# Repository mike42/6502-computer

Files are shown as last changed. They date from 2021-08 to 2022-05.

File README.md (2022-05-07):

# 6502 computer

This repository contains the hardware and software for my home-built 65C02-based computer. At its heart, this computer is a 1980's design, and is approximately as powerful as the Apple II. It is powered over USB, and operated via a serial connection.

It features an SD card interface, simple audio interface, and two user-selectable ROMs. One ROM contains a port of EhBASIC, which is the only proprietary component in this repository. The other ROM contains a shell, written from scratch to be free and open source, which can be used to load machine-language programs from a modern PC.

Take a look at the [hardware/](https://github.com/mike42/6502-computer/tree/main/hardware) directory for how it's made, or [rom/](https://github.com/mike42/6502-computer/tree/main/rom) for the firmware source code.

### Basic specs

- 1.8432 MHz 65C02 processor
- 32 KiB RAM
- 32 KiB ROM in two 16 KiB banks
- 65C22 VIA (general purpose I/O) chip
- 65C51N ACIA (UART) interface
- Custom PCB and 3D printed case

### Image of completed build

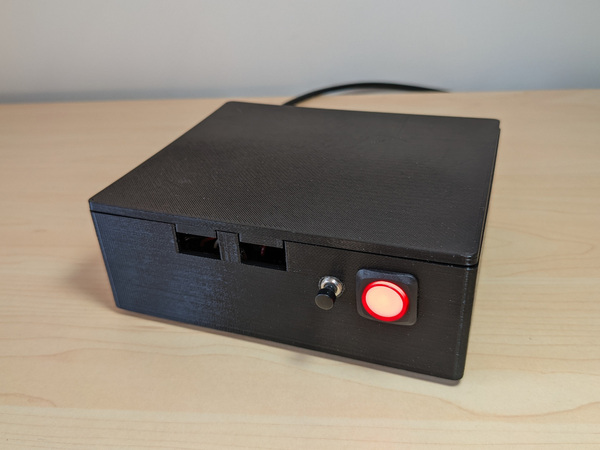
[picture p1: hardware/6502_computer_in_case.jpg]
Completed project


## Blog series

This project started out on breadboards, and I have been blogging about it as I have progressed the hardware, software, and my electronics knowlege. Posts I've written about this project include:

- [IntelliJ plugin for 6502 assembly language](https://mike42.me/blog/2021-05-intellij-plugin-for-6502-assembly-language)
- [Building a 6502 computer](https://mike42.me/blog/2021-07-building-a-6502-computer)
- [Adding a serial port to my 6502 computer](https://mike42.me/blog/2021-07-adding-a-serial-port-to-my-6502-computer)
- [Upgrades and improvements to my 6502 computer](https://mike42.me/blog/2021-08-upgrades-and-improvements-to-my-6502-computer)
- [Porting BASIC to my 6502 computer](https://mike42.me/blog/2021-09-porting-basic-to-my-6502-computer)
- [6502 computer – from breadboard to PCB](https://mike42.me/blog/2021-09-6502-computer-from-breadboard-to-pcb)
- [Re-creating the world’s worst sound card](https://mike42.me/blog/2021-10-re-creating-the-worlds-worst-sound-card)
- [Designing a 3D printed enclosure for my KiCad project in Blender](https://mike42.me/blog/2021-11-designing-a-3d-printed-enclosure-for-my-kicad-project-in-blender)
- [Implementing the XMODEM protocol for file transfer](https://mike42.me/blog/2021-12-implementing-the-xmodem-protocol-for-file-transfer)
- [Adding an SD card reader to my 6502 computer](https://mike42.me/blog/2021-12-adding-an-sd-card-reader-to-my-6502-computer)
- [Assembling my 6502 computer](https://mike42.me/blog/2012-12-assembling-my-6502-computer)
- [Rendering my 6502 computer project in Blender](https://mike42.me/blog/2022-01-rendering-my-6502-computer-project-in-blender)

## Licenses & acknowledgement

With the exception of the files noted below, this work is © 2021 Michael Billington, and is licensed under a [Creative Commons Attribution 4.0 International License](http://creativecommons.org/licenses/by/4.0/).

The design is an extension of [Ben Eater's 6502 computer tutorial](https://eater.net/6502), which is itself based on the work of the [6502.org](http://www.6502.org/) community.

### 6502 KiCad Library

The files `hardware/kicad/65xx.dcm` and `hardware/kicad/65xx.lib` are modified versions of the [6502 KiCad Library](https://github.com/Alarm-Siren/6502-kicad-library). Copyright 2018, Nicholas Parks Young. All Rights Reserved. The 6502 KiCad Library library is licensed under the GNU LGPL v2.1, which can be found in file `licenses/LGPL.txt`.

### EhBASIC

The files in `rom/basic/` are derived from EhBASIC, developed by Lee Davidson. The EhBASIC license allows for non-commerical use only. The most recent release and manual is hosted [here](https://github.com/Klaus2m5/6502_EhBASIC_V2.22), and a mirror of Lee's website can be found [here](http://retro.hansotten.nl/6502-sbc/lee-davison-web-site/).

> EhBASIC is free but not copyright free. For non commercial use there is only one
> restriction, any derivative work should include, in any binary image distributed,
> the string "Derived from EhBASIC" and in any distribution that includes human
> readable files a file that includes the above string in a human readable form
> e.g. not as a comment in an HTML file.

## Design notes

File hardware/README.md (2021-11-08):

# 6502 computer hardware

This directory contains information about the hardware side of this project.

- [kicad/](https://github.com/mike42/6502-computer/tree/main/hardware/kicad) - CAD source files for schematic and PCB
- [gerber/](https://github.com/mike42/6502-computer/tree/main/hardware/gerber/) - PCB manufacturing files 
- [6502_computer_schematic.pdf](https://github.com/mike42/6502-computer/tree/main/hardware/6502_computer_schematic.pdf) - Human-readable schematic
- [case/](https://github.com/mike42/6502-computer/tree/main/hardware/case/) - STL files for 3D printed computer case.
- Parts list (below)

## Parts list for assembling PCB

This is the full list of parts which are required to fully populate the PCB for this build. I've stuck with the parts which I actually used, though many can be substituted if you check the data sheets.

PCB diagram

### IC’s and sockets

Notes on IC's and sockets

- If you see a designator mentioned twice, one is the IC, the other is the socket.
- All sockets are optional except U9.

| Qty. | Description | Installed at | Product ref. |
| ---- | --- | --- | --- |
| 1  | 65C02S CPU | U1 | [WDC W65C02S6TPG-14](https://au.mouser.com/ProductDetail/955-W65C02S6TPG-14) |
| 1  | 65C22S VIA | U3 | [WDC W65C22S6TPG-14](https://au.mouser.com/ProductDetail/955-W65C22S6TPG-14) |
| 2  | DIP-40 socket | U1, U3 | [Mill-Max 110-99-640-41-001000](https://au.mouser.com/ProductDetail/575-199640) |
| 1  | 65C51N ACIA | U6 | [WDC W65C51N6TPG-14](https://au.mouser.com/ProductDetail/955-W65C51N6TPG-14) |
| 1  | SRAM 32k x 8 | U8 | [Alliance AS6C62256-55PCN](https://au.mouser.com/ProductDetail/913-AS6C62256-55PCN)  |
| 2  | DIP-28 socket | U6, U8 | [Mill-Max 110-99-628-41-001000](https://au.mouser.com/ProductDetail/575-199628) |
| 1  | EEPROM 32k x 8 | U9 | [Atmel AT28C256-15PU](https://au.mouser.com/ProductDetail/556-AT28C25615PU) |
| 1  | Low-profile DIP-28 ZIF socket  | U9 | [Aires 28-526-10](https://au.mouser.com/ProductDetail/535-28-526-10) |
| 1  | 74LS138 demultiplexer | U2 | [Texas Instruments SN74LS138N](https://au.mouser.com/ProductDetail/595-SN74LS138N) |
| 1  | DIP-16 socket | U2 | [Mill-Max 110-44-316-41-001000](https://au.mouser.com/ProductDetail/575-11044316) |
| 1  | 74LS00 quad NAND gate | U4 | [Texas Instruments SN74LS00N](https://au.mouser.com/ProductDetail/595-SN74LS00N) |
| 1  | DIP-14 socket | U4 | [Mill-Max 110-44-314-41-001000](https://au.mouser.com/ProductDetail/575-11044314) |
| 1  | 1.8432 MHz oscillator | X1 | [CTS MXO45HS-3C-1M8432](https://au.mouser.com/ProductDetail/774-MXO45HS-3C-1.8) |
| 1  | Oscillator socket | X1 | [Aires 1108800](https://au.mouser.com/ProductDetail/535-1108800) |
| 1  | 7805 voltage regulator | U5 | [STMicroelectronics L7805ABV](https://au.mouser.com/ProductDetail/511-L7805ABV) |
| 1  | DS1813 reset / voltage monitor | U7 | [Maxim Integrated DS1813-5+](https://au.mouser.com/ProductDetail/700-DS1813-5%2b) |

### Connectors

Notes on connectors:

- If you use the exact parts here, then one of the 2x20 headers needs to be snapped apart to populate 2x6 footprints at J4 and J5.
- The shunts at J3 should be installed to connect the VIA to IRQ, and the ACIA to NMI. These are labelled on the PCB.

| Qty. | Description | Installed at | Product ref. |
| ---- | --- | --- | --- |
| 2 | 2x20 male pin header | J1, J4, J5 | [Amphenol FCI 10129381-940002BLF](https://au.mouser.com/ProductDetail/649-1012938194002BLF) |
| 1 | Barrel jack | J2 | [Adafruit 373](https://au.mouser.com/ProductDetail/485-373) |
| 1 | 1x6 male pin header | J6 | [Amphenol FCI 10129378-906001BLF](https://au.mouser.com/ProductDetail/Amphenol-FCI/10129378-906001BLF) |
| 2 | SPDT switch 2.54mm lead spacing | SW1, SW2 | [SparkFun COM-00102](https://au.mouser.com/ProductDetail/474-COM-00102) |
| 1 | Momentary switch | SW3 | [SparkFun COM-00097](https://au.mouser.com/ProductDetail/474-COM-00097) |
| 2 | 1x2 male pin header | J3 | [Amphenol FCI 10129378-902001BLF](https://au.mouser.com/ProductDetail/649-1012937890201BLF) |
| 2 | Shunt/jumper | J3 | [TE Connectivity 2-382811-1](https://au.mouser.com/ProductDetail/571-2-382811-1) |

### Basic components

| Qty. | Description | Installed at | Product ref. |
| ---- | --- | --- | --- |
| 1 | 0.1 µF ceramic capacitor, 2.54mm lead spacing (10 pack) | C1, C2, C3, C4, C5, C6, C7, C8, C10  | [Adafruit 753](https://au.mouser.com/ProductDetail/485-753) |
| 1 | 1 µF electrolytic capacitor, 1.5mm lead spacing | C9 | – |
| 1 | 1N5819 schottky diode | D1 | – |
| 1 | 5.0 mm LED | D2 | – |
| 3 | 3.3 kΩ resistor 1/4w | R1 R2 R4 | – |
| 1 | 1 kΩ resistor 1/4w | R3 | – |

## Additional parts to install in case

| Qty. | Description | Product ref. |
| ---- | --- | --- |
| 1 | 16mm Illuminated Pushbutton - Red Latching On/Off Switch | [Adafruit 1442](https://core-electronics.com.au/16mm-illuminated-pushbutton-red-latching-on-off-switch.html) |
| 1 | 330 Ω resistor 1/4w | – |
| 1 | Momentary Button - Panel Mount | [SparkFun COM-11006](https://core-electronics.com.au/momentary-button-panel-mount-black.html) |
| 1 | Piezo Buzzer | [TDK PS1240P02BT](https://core-electronics.com.au/piezo-buzzer-ps1240.html) |
| 4 | M3 x 5+6mm hex standoff | Generic, similar to [this](https://www.minikits.com.au/SPA-M3x5-6-B-C) |
| 4 | M3 nut | [Polulu 1069](https://core-electronics.com.au/machine-hex-nut-m3-25-pack.html) |
| 4 | M3 x 5 mm screw | [Polulu 1075](https://core-electronics.com.au/machine-screw-m3-5mm-length-phillips-25-pack.html) |
| 1 | Heat-shrink tubing kit | [Adafruit 344](https://core-electronics.com.au/heat-shrink-pack.html) |
| 1 | Stranded wire | – |
| 1 | Du Pont connector kit | – |
| 1 | FTDI Cable 5V (FT232RQ-based) | [Sparkfun DEV-09718](https://core-electronics.com.au/ftdi-cable-5v.html) |
| 1 | Adhesive rubber feet | [Adafruit 550](https://core-electronics.com.au/little-rubber-bumper-feet-pack-of-4.html) |

### Case installation notes

First solder three pairs of wires to the underside of the PCB for adding connectors. Each wire is soldered to the PCB on one end, with a female Du Pont connector on the other end (2 x 1 housing).

- Power: Attach to pins 1 and 2 of SW1 to control DC barrel jack, or attach between Pin 4 of J6 (labelled `NC`) and Pin 1 of J5 (labelled `5V`) for power over USB.
- Reset: Connect to underside of SW3. One wire should attach to `GND`, the other to `RES`.
- Speaker: Connect to underside of J1, at pins 24 (labelled `IO2`) and pin 2 (labelled `GND`).

Next, add the corresponding connectors to the power/reset buttons and speaker.

- Power: Solder a wire to each power terminal, and terminate it to a 2x1 male Du Point connector. Solder a wire to each LED terminal, adding a resistor on the GND line, and terminating them to a 2x1 female Du Pont connector.
- Reset: Solder wire to each terminal, terminate to a 2x1 male Du Pont connector
- Speaker: Solder wire to each terminal, terminate to a 2x1 male Du Pont connector

To assemble, first check that the reset button fits (the hole is too small in the case model, and will need to be expanded). Install stand-offs, then feed the UART cable through the oval-shaped hole. Next, add the PCB, and install the power and reset buttons. After this, you can connect the UART cable, power button, and reset button to the board. The power LED connects to pin 1 and 2 of J5. The final step is to super-glue the speaker over the hole at the back of the case.

## Additional parts to install microSD

Some of the test programs in this repository expect an SD card to be connected. Any 5V-compatible microSD break-out board could be used. These exact parts will fit inside the case with the lid closed.

| Qty. | Description | Product ref. |
| ---- | --- | --- |
| 1 | Level Shifting microSD Breakout | [Sparkfun DEV-13743](https://core-electronics.com.au/sparkfun-level-shifting-microsd-breakout.html) |
| 1 | 1x7 male pin header | Generic, similar to [this](https://au.mouser.com/ProductDetail/Amphenol-FCI/10129378-907001BLF) |
| 1 | 1x7 female pin header | [Polulu 1017](https://core-electronics.com.au/0-100-2-54-mm-female-header-1x7-pin-straight.html) |
| 1 | 2x6 female Du Pont housing | [Polulu 1914](https://core-electronics.com.au/0-1-2-54mm-crimp-connector-housing-2x6-pin-5-pack.html) |
| 1 | microSD card 16 GB | – |

### microSD installation notes

These parts can be used to install a microSD card in the case, attaching to J4. The card sits parallel to J4.

Glue the female pin header to the side of the Du Pont housing to make an adapter. You will need 6 wires, soldered on one end, and with a female Du Pont connector on the other end:

- Pin 1 (labelled `5V`) connects to `VCC`
- Pin 2 (labelled `GND`) connects to `GND`
- Pin 5 (labelled `PA0`) connects to `DO`
- Pin 6 (labelled `PA1`) connects to `SCK`
- Pin 7 (labelled `PA2`) connects to `DI`
- Pin 8 (labelled `PA3`) connects to `CS`

Solder the male pin headers to the microSD breakout, connect the module to the adapter, and attach it to J4. Wiggle it around a bit, and add insulating tape to anything it can contact. You can then fit an SD card.

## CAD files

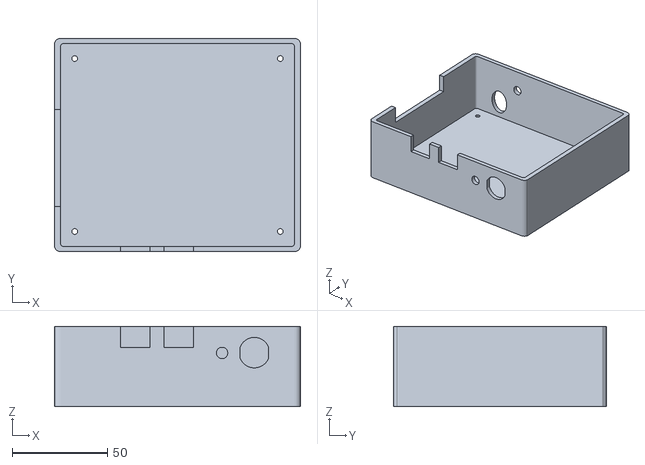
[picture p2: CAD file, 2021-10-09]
hardware/case/base.stl
128.8 x 111.7 x 42.0

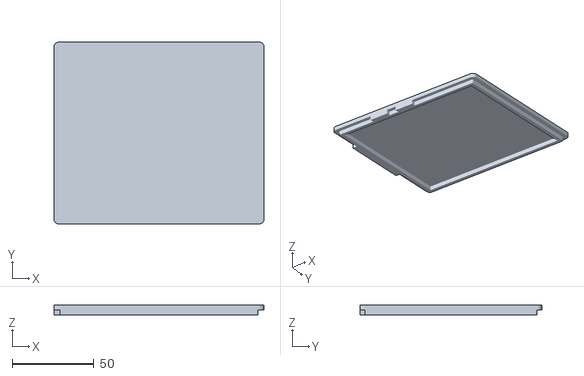
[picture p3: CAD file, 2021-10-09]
hardware/case/lid.stl
128.8 x 111.7 x 6.00

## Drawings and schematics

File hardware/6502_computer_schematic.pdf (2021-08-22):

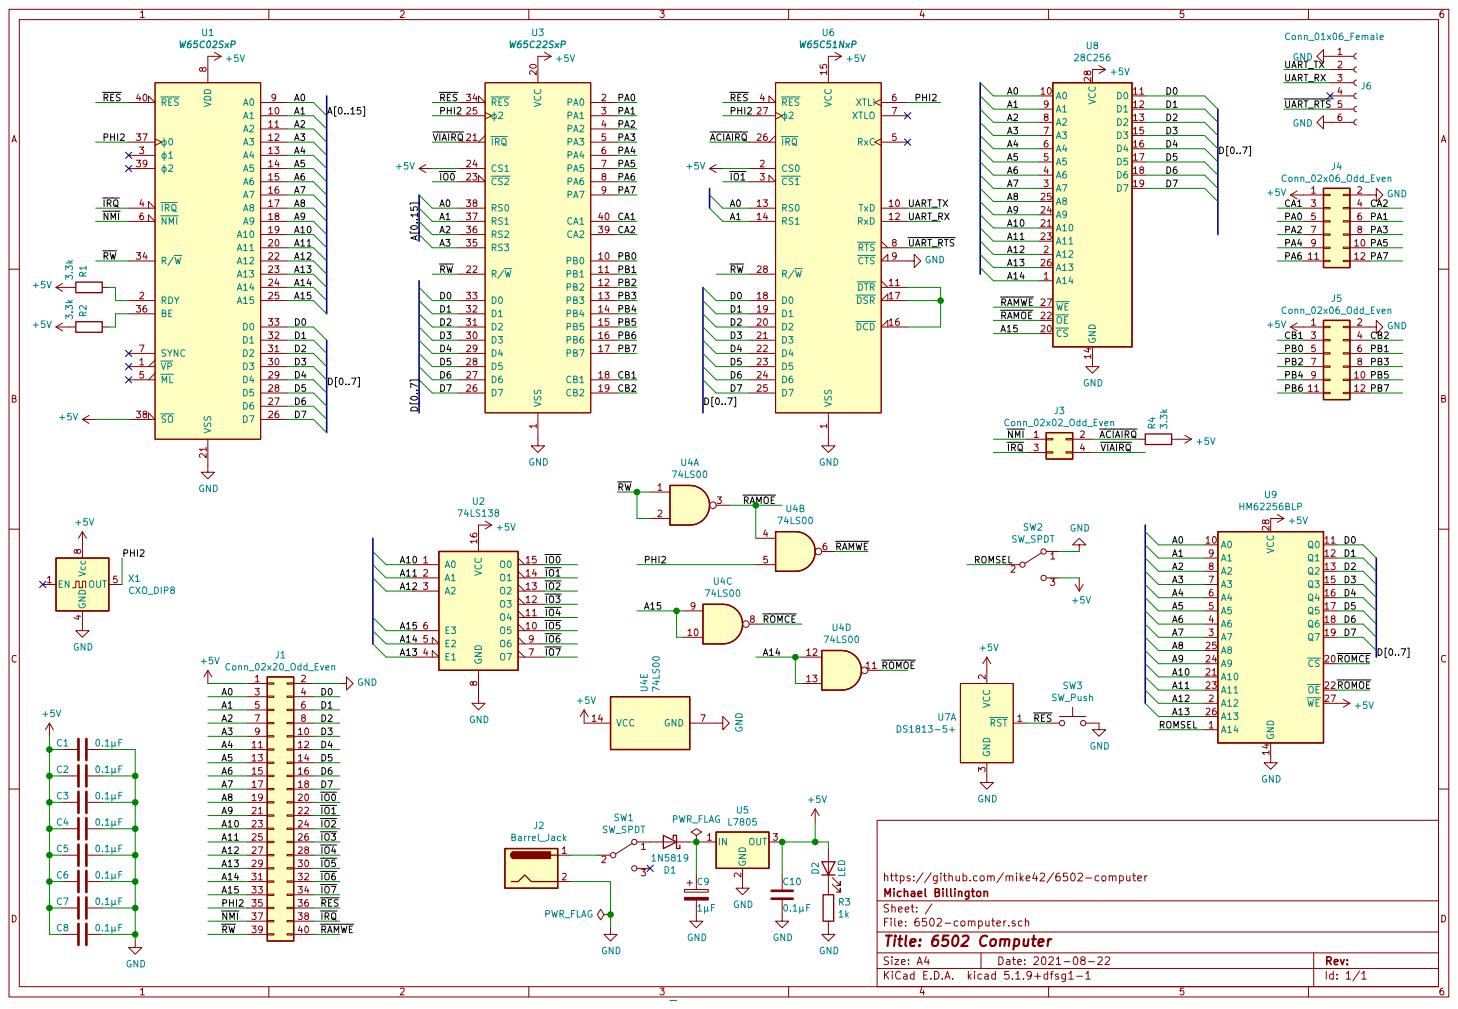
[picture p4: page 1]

1 TxD 10 DTR 11 RxD 12 RS0 13 RS1 14 VCC 15 DCD 16 DSR 17 D0 18 D1 19 CS0 2 D2 20 D3 21 D4 22 D5 23 D6 24 D7 25

4 OUT 5 Vcc 8 X1CXO_DIP8 GND 14 VCC 28 A14 1 A0 10 Q0 11 Q1 12 Q2 13 Q3 15 Q4 16 Q5 17 Q6 18 Q7 19 A12 2 CS 20 A10 21 OE 22 A11 23 A9 24 A8 25 A13 26 WE 27 A7 3 A6 4 A5 5 A4 6 A3 7 A2 8 A1 9 U9 HM62256BLP

https://github.com/mike42/6502-computer
File: 6502-computer.sch Sheet: / Michael Billington

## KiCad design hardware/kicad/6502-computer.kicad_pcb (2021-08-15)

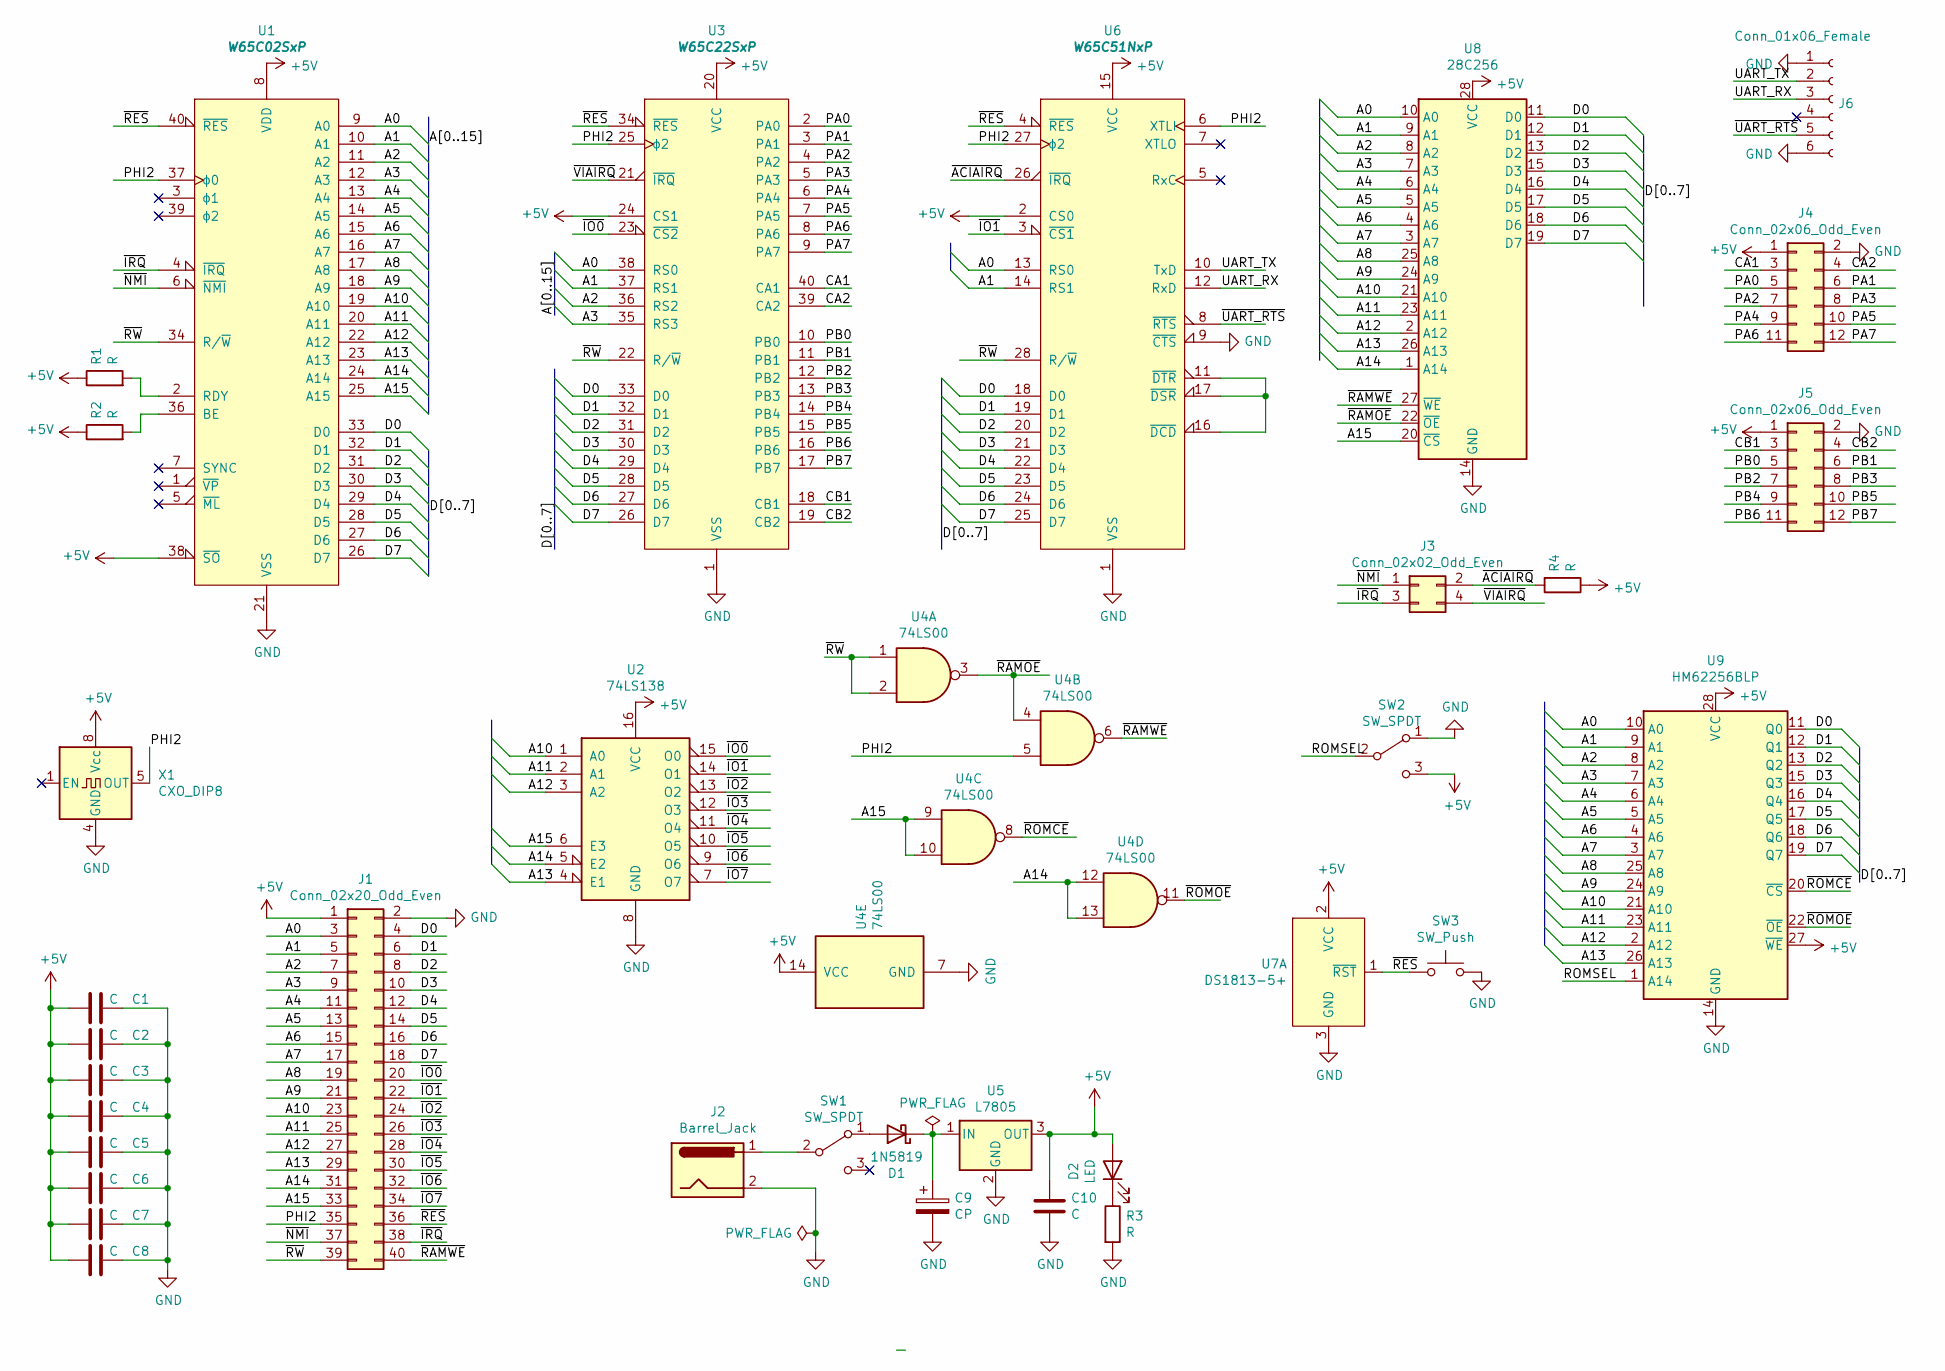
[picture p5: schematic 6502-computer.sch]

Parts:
C1, C2, C3, C4, C5, C6, C7, C8, C10: C; C_Disc_D5.0mm_W2.5mm_P2.50mm
C9: CP; C_Radial_D4.0mm_H7.0mm_P1.50mm
D1: 1N5819; D_DO-41_SOD81_P10.16mm_Horizontal
D2: LED; LED_D5.0mm
J1: Conn_02x20_Odd_Even; PinHeader_2x20_P2.54mm_Vertical
J2: Barrel_Jack; BarrelJack_Horizontal
J3: Conn_02x02_Odd_Even; PinHeader_2x02_P2.54mm_Vertical
J4, J5: Conn_02x06_Odd_Even; PinHeader_2x06_P2.54mm_Vertical
J6: Conn_01x06_Female; PinHeader_1x06_P2.54mm_Vertical
R1, R2, R3, R4: R; R_Axial_DIN0207_L6.3mm_D2.5mm_P10.16mm_Horizontal
SW1, SW2: SW_SPDT; SW_THT_DPDT
SW3: SW_Push; SW_Tactile_Straight_KSL0Axx1LFTR
U1: W65C02SxP; DIP-40_W15.24mm_Socket
U2: 74LS138; DIP-16_W7.62mm_Socket
U3: W65C22SxP; DIP-40_W15.24mm_Socket
U4: 74LS00; DIP-14_W7.62mm_Socket
U5: L7805; TO-220-3_Horizontal_TabDown
U6: W65C51NxP; DIP-28_W15.24mm_Socket
U7: DS1813-5+; TO-92
U8: 28C256; DIP-28_W15.24mm_Socket
U9: HM62256BLP; DIP-28_W15.24mm_Socket
X1: CXO_DIP8; Oscillator_DIP-8

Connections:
+5V: C1.2, C2.2, C3.2, C4.2, C5.2, C6.2, C7.2, C8.2, C10.1, D2.2 (A), J1.1, J4.1, J5.1, R1.1, R2.1, R4.1, SW2.3 (C), U1.8 (VDD), U1.38 (~SO), U2.16 (VCC), U3.20 (VCC), U3.24 (CS1), U4.14 (VCC), U5.3 (OUT), U6.2 (CS0), U6.15 (VCC), U7.2 (VCC), U8.28 (VCC), U9.27 (~WE), U9.28 (VCC), X1.8 (Vcc)
/A0: J1.3, U1.9 (A0), U3.38 (RS0), U6.13 (RS0), U8.10 (A0), U9.10 (A0)
/A1: J1.5, U1.10 (A1), U3.37 (RS1), U6.14 (RS1), U8.9 (A1), U9.9 (A1)
/A2: J1.7, U1.11 (A2), U3.36 (RS2), U8.8 (A2), U9.8 (A2)
/A3: J1.9, U1.12 (A3), U3.35 (RS3), U8.7 (A3), U9.7 (A3)
/A4: J1.11, U1.13 (A4), U8.6 (A4), U9.6 (A4)
/A5: J1.13, U1.14 (A5), U8.5 (A5), U9.5 (A5)
/A6: J1.15, U1.15 (A6), U8.4 (A6), U9.4 (A6)
/A7: J1.17, U1.16 (A7), U8.3 (A7), U9.3 (A7)
/A8: J1.19, U1.17 (A8), U8.25 (A8), U9.25 (A8)
/A9: J1.21, U1.18 (A9), U8.24 (A9), U9.24 (A9)
/A10: J1.23, U1.19 (A10), U2.1 (A0), U8.21 (A10), U9.21 (A10)
/A11: J1.25, U1.20 (A11), U2.2 (A1), U8.23 (A11), U9.23 (A11)
/A12: J1.27, U1.22 (A12), U2.3 (A2), U8.2 (A12), U9.2 (A12)
/A13: J1.29, U1.23 (A13), U2.4 (E1), U8.26 (A13), U9.26 (A13)
/A14: J1.31, U1.24 (A14), U2.5 (E2), U4.12, U4.13, U8.1 (A14)
/A15: J1.33, U1.25 (A15), U2.6 (E3), U4.9, U4.10, U8.20 (~CS)
/CA1: J4.3, U3.40 (CA1)
/CA2: J4.4, U3.39 (CA2)
/CB1: J5.3, U3.18 (CB1)
/CB2: J5.4, U3.19 (CB2)
/D0: J1.4, U1.33 (D0), U3.33 (D0), U6.18 (D0), U8.11 (D0), U9.11 (Q0)
/D1: J1.6, U1.32 (D1), U3.32 (D1), U6.19 (D1), U8.12 (D1), U9.12 (Q1)
/D2: J1.8, U1.31 (D2), U3.31 (D2), U6.20 (D2), U8.13 (D2), U9.13 (Q2)
/D3: J1.10, U1.30 (D3), U3.30 (D3), U6.21 (D3), U8.15 (D3), U9.15 (Q3)
/D4: J1.12, U1.29 (D4), U3.29 (D4), U6.22 (D4), U8.16 (D4), U9.16 (Q4)
/D5: J1.14, U1.28 (D5), U3.28 (D5), U6.23 (D5), U8.17 (D5), U9.17 (Q5)
/D6: J1.16, U1.27 (D6), U3.27 (D6), U6.24 (D6), U8.18 (D6), U9.18 (Q6)
/D7: J1.18, U1.26 (D7), U3.26 (D7), U6.25 (D7), U8.19 (D7), U9.19 (Q7)
/PA0: J4.5, U3.2 (PA0)
/PA1: J4.6, U3.3 (PA1)
/PA2: J4.7, U3.4 (PA2)
/PA3: J4.8, U3.5 (PA3)
/PA4: J4.9, U3.6 (PA4)
/PA5: J4.10, U3.7 (PA5)
/PA6: J4.11, U3.8 (PA6)
/PA7: J4.12, U3.9 (PA7)
/PB0: J5.5, U3.10 (PB0)
/PB1: J5.6, U3.11 (PB1)
/PB2: J5.7, U3.12 (PB2)
/PB3: J5.8, U3.13 (PB3)
/PB4: J5.9, U3.14 (PB4)
/PB5: J5.10, U3.15 (PB5)
/PB6: J5.11, U3.16 (PB6)
/PB7: J5.12, U3.17 (PB7)
/PHI2: J1.35, U1.37 (ϕ0), U3.25 (ϕ2), U4.5, U6.6 (XTLI), U6.27 (ϕ2), X1.5 (OUT)
/ROMSEL: SW2.2 (B), U9.1 (A14)
/UART_RX: J6.3, U6.12 (RxD)
/UART_TX: J6.2, U6.10 (TxD)
/~ACIAIRQ: J3.2, R4.2, U6.26 (~IRQ)
/~IO0: J1.20, U2.15 (O0), U3.23 (~CS2)
/~IO1: J1.22, U2.14 (O1), U6.3 (~CS1)
/~IO2: J1.24, U2.13 (O2)
/~IO3: J1.26, U2.12 (O3)
/~IO4: J1.28, U2.11 (O4)
/~IO5: J1.30, U2.10 (O5)
/~IO6: J1.32, U2.9 (O6)
/~IO7: J1.34, U2.7 (O7)
/~IRQ: J1.38, J3.3, U1.4 (~IRQ)
/~NMI: J1.37, J3.1, U1.6 (~NMI)
/~RAMOE: U4.3, U4.4, U8.22 (~OE)
/~RAMWE: J1.40, U4.6, U8.27 (~WE)
/~RES: J1.36, SW3.1, U1.40 (~RES), U3.34 (~RES), U6.4 (~RES), U7.1 (~RST)
/~ROMCE: U4.8, U9.20 (~CS)
/~ROMOE: U4.11, U9.22 (~OE)
/~RW: J1.39, U1.34 (R/~W), U3.22 (R/~W), U4.1, U4.2, U6.28 (R/~W)
/~UART_RTS: J6.5, U6.8 (~RTS)
/~VIAIRQ: J3.4, U3.21 (~IRQ)
GND: C1.1, C2.1, C3.1, C4.1, C5.1, C6.1, C7.1, C8.1, C9.2, C10.2, J1.2, J2.2, J4.2, J5.2, J6.1, J6.6, R3.2, SW2.1 (A), SW3.2, U1.21 (VSS), U2.8 (GND), U3.1 (VSS), U4.7 (GND), U5.2 (GND), U6.1 (VSS), U6.9 (~CTS), U7.3 (GND), U8.14 (GND), U9.14 (GND), X1.4 (GND); also elsewhere on the board
unnamed: C9.1, D1.1 (K), U5.1 (IN)
unnamed: D1.2 (A), SW1.1 (A)
unnamed: D2.1 (K), R3.1
unnamed: J2.1, SW1.2 (B)
unnamed: R1.2, U1.2 (RDY)
unnamed: R2.2, U1.36 (BE)
unnamed: U6.11 (~DTR), U6.16 (~DCD), U6.17 (~DSR)

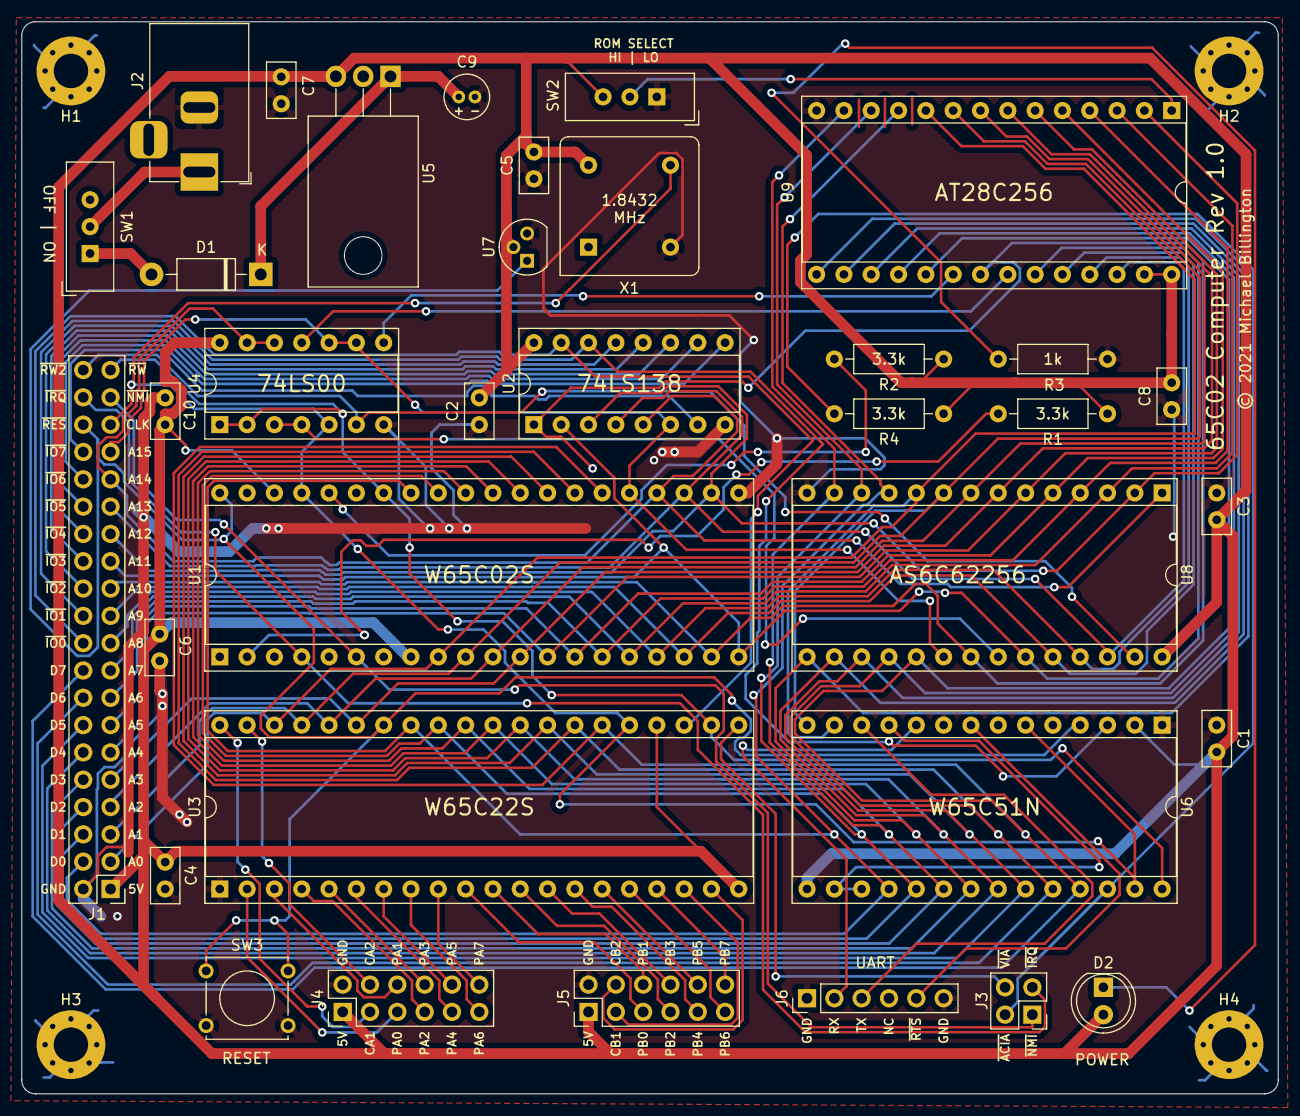
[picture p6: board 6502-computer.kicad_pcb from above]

Board: 2 copper layers, 116.8 x 99.7 mm, 39 parts (0 on the bottom side), 76 nets.

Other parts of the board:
H1, H2, H3, H4: MountingHole_3.2mm_M3_Pad_Via

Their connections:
GND: H1.1, H2.1, H3.1, H4.1; also elsewhere on the board

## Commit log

2021-08-15 Initial commit, schematic + gerbers
    [6502-computer-B_Cu.gbl, 6502-computer-B_Mask.gbs, 6502-computer-B_Paste.gbp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]
2021-08-15 modify for ca65 assembly to 16KiB ROM, loaded from $c000, 65c51 ACIA, 65c02 CPU target
    [sbc.cfg]
2021-08-22 add component values
    [6502-computer.sch]
2021-08-22 add PDF schematic, parts list
    [6502-computer.sch]
2021-08-24 update assembly files, add firmware for high ROM.
    [sbc.cfg]
2021-09-29 restructure for custom programs
    [basic.cfg, boot.cfg, program.cfg]
2021-09-29 more changes to support programs outside ROM
    [program.cfg]
2021-10-01 split programs out of boot ROM directory
    [boot.cfg, program.cfg]
2021-10-03 firmware fixes, first attempt at SPI/SD card interface
2021-10-03 second attempt at SPI/SD card interface
2021-10-04 update SD card test code, add new linker config
    [program.cfg]
2021-10-09 add case STL files
    [base.stl, lid.stl]
2021-10-11 add PCB diagram
2021-11-08 add case install notes
